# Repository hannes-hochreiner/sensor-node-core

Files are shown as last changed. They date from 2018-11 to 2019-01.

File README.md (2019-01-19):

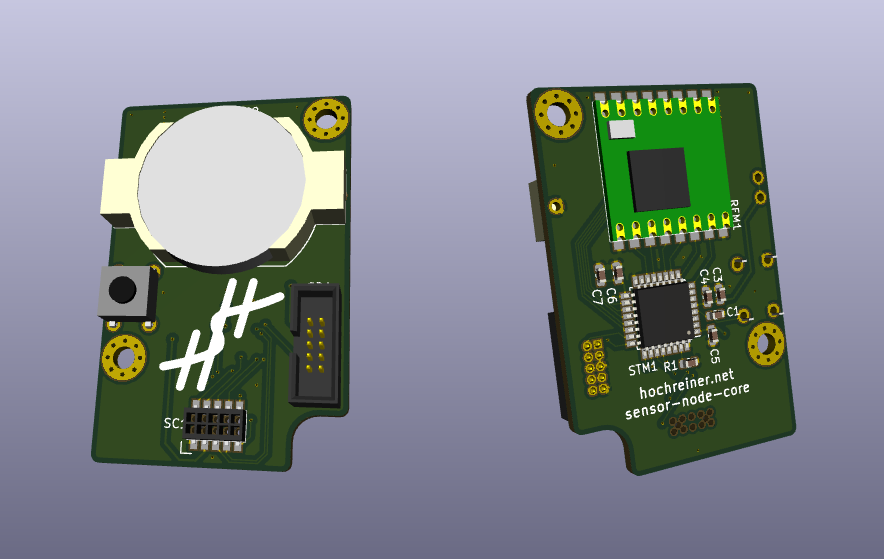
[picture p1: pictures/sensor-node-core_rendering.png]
kicad rendering of the sensor node core


# Sensor Node Core

This is another take on the sensor node theme.
I am planning on separating the core form the actual sensor.
The core will contain the micro-controller (incl. debug connector and reset button), radio (incl. antenna), and battery, as well as a connector providing power, SPI, I2C, and GPIOs.

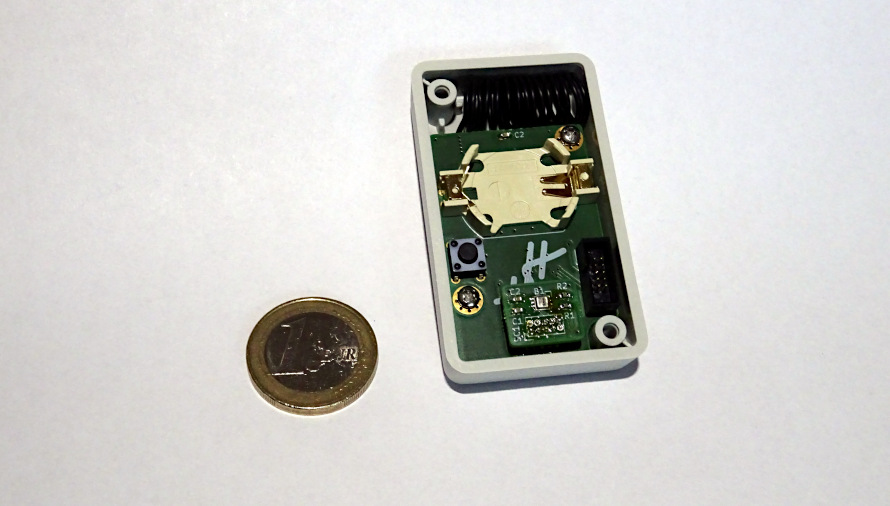
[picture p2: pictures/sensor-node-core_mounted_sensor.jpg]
sensor node core mounted in a plastic box with sensor


## Main parts

### STM32
  * STMicroelectronics: STM32L021K4T6
  * Digi-Key: [497-17903-ND](https://www.digikey.de/product-detail/de/stmicroelectronics/STM32L021K4T6/497-17903-ND)
  * [datasheet](http://www.st.com/content/ccc/resource/technical/document/datasheet/86/a6/5f/95/33/50/4e/d6/DM00206858.pdf/files/DM00206858.pdf/jcr:content/translations/en.DM0020685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)
  * Sleep Current: 0.54 µA
  * Price: 1.87

### RFM98
  * Seeed Technology Co., Ltd: 109990165
  * Digi-Key: [1597-1491-ND](https://www.digikey.de/product-detail/de/seeed-technology-co-ltd/109990165/1597-1491-ND)
  * [datasheet](https://github.com/SeeedDocument/RFM95-98_LoRa_Module/blob/master/RFM95_96_97_98_DataSheet.pdf)
  * Sleep Current: 0.2 µA
  * Price: 6.05

### Box
  * Hammond Manufacturing: 1551JGY
  * Digi-Key: [HM1133-ND](https://www.digikey.de/product-detail/de/hammond-manufacturing/1551JGY/HM1133-ND/2094871)
  * [Datasheet](http://www.hammondmfg.com/pdf/1551J.pdf)
  * Price: 2.09

### SWD Connector
  * CNC Tech: 3220-10-0100-00
  * Digi-Key: [1175-1627-ND](https://www.digikey.de/product-detail/en/cnc-tech/3220-10-0100-00/1175-1627-ND/3883661)
  * Price: 0.51

### 10-pin Sensor Connector
  * Harwin Inc.: M50-3150542R
  * Digi-Key: [952-3493-1-ND](https://www.digikey.de/product-detail/en/harwin-inc/M50-3150542R/952-3493-1-ND/6797677)
  * [Datasheet](https://cdn.harwin.com/pdfs/M50-315R.pdf)
  * Price: 2.27

### Coin Cell Holder
  * MPD (Memory Protection Devices): BU2032-1-G
  * Digi-Key: [BU2032-1-G-ND](https://www.digikey.de/product-detail/en/mpd-memory-protection-devices/BU2032-1-G/BU2032-1-G-ND/2439519)
  * [Datasheet](http://www.memoryprotectiondevices.com/datasheets/BU2032-1-G-datasheet.pdf)
  * Price: 0.89

### Button
  * TE Connectivity ALCOSWITCH Switches: 1825910-6
  * Digi-Key: [450-1650-ND](https://www.digikey.de/product-detail/en/te-connectivity-alcoswitch-switches/1825910-6/450-1650-ND/1632536)
  * [Datasheet](https://www.te.com/commerce/DocumentDelivery/DDEController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)
  * Price: 0.09

## Price

Estimate: about 20 EUR

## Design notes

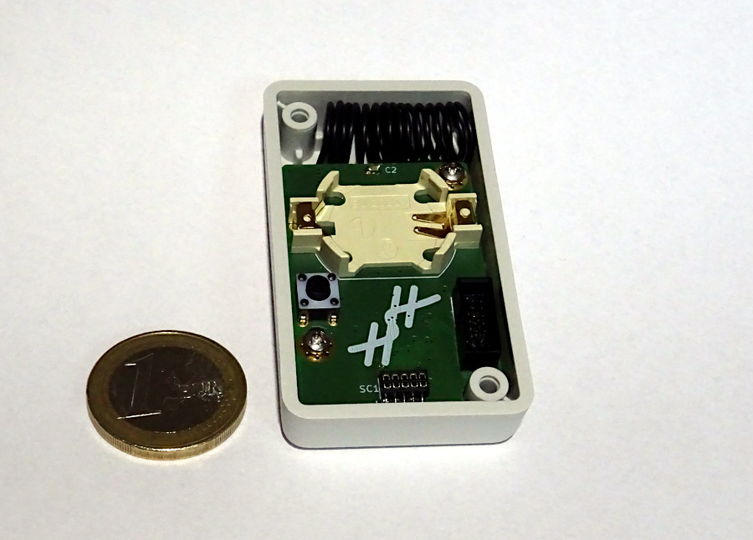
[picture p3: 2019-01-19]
pictures/sensor-node-core_mounted.jpg

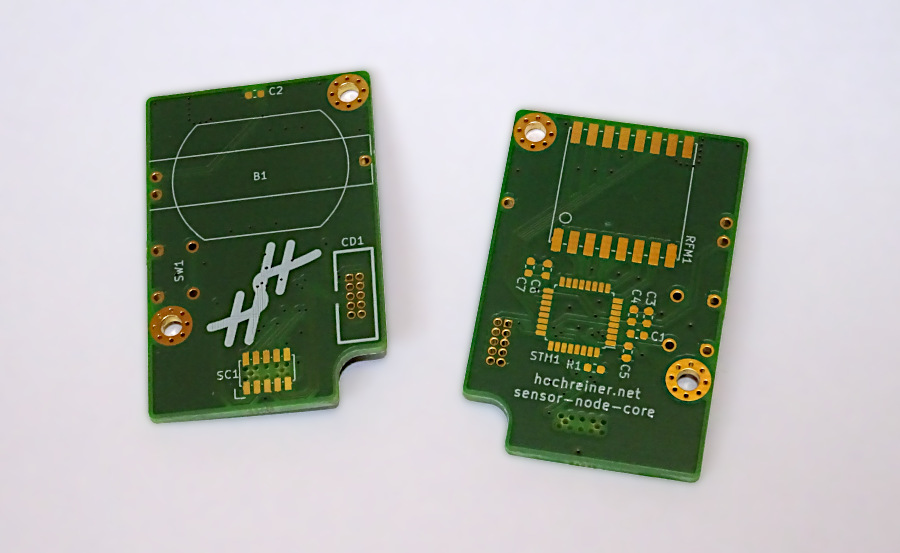
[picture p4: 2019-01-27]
pictures/sensor-node-core_pcb.jpg

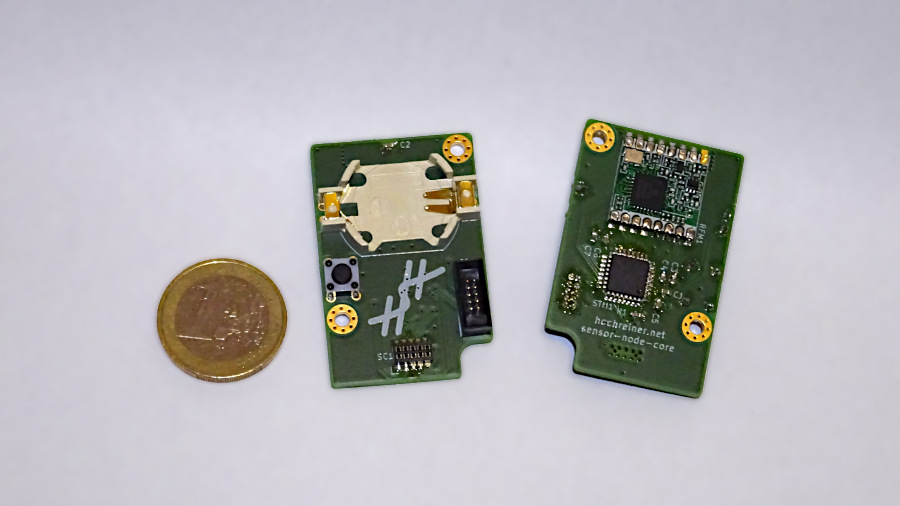
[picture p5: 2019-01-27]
pictures/sensor-node-core_populated.jpg

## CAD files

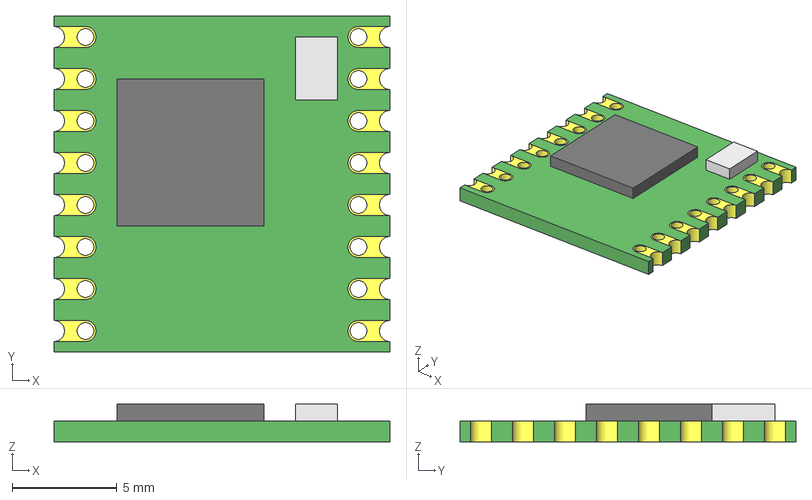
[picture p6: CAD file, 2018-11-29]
freecad/RFM98.step
16.0 x 16.0 x 1.80 mm

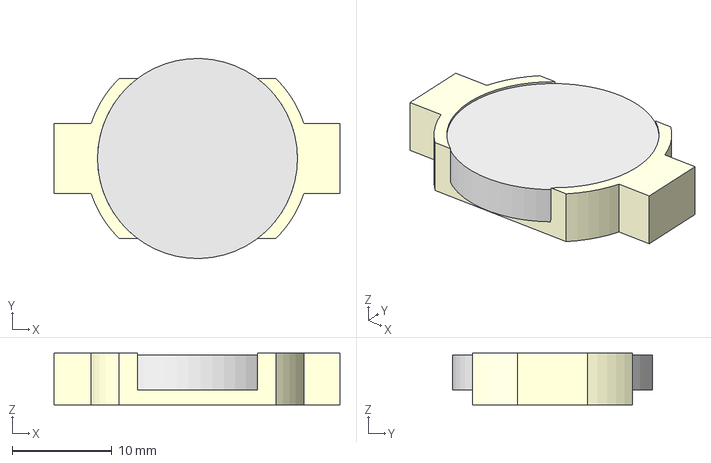
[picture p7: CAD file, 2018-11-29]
freecad/BU2032-1-G.step
28.6 x 20.0 x 5.20 mm

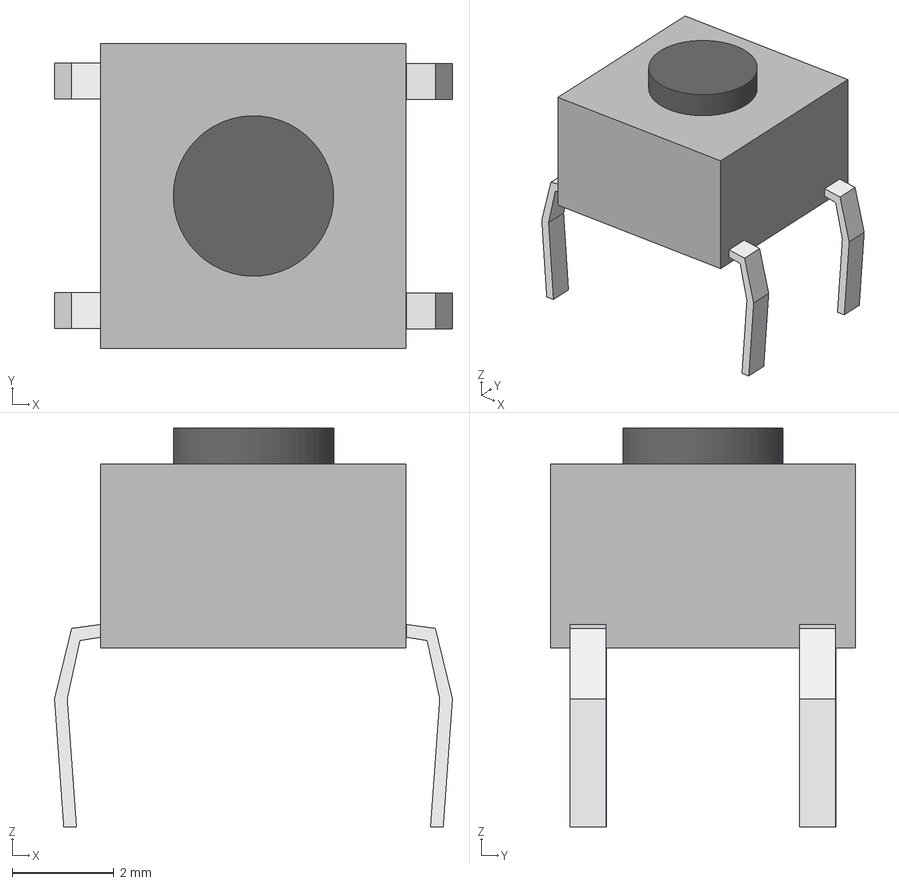
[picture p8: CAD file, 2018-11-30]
freecad/1825910-6.step
7.81 x 5.99 x 7.82 mm

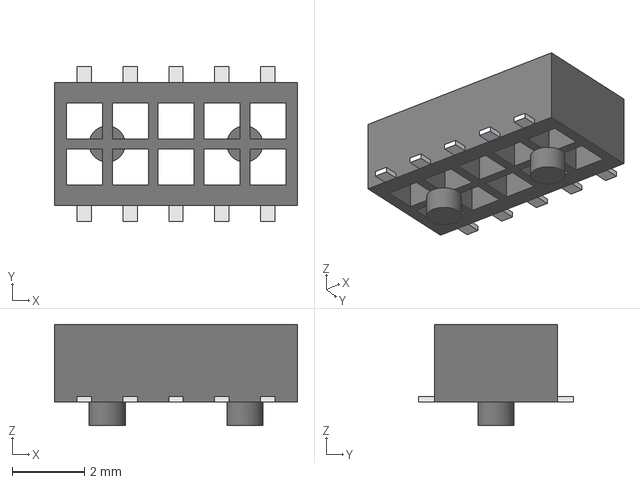
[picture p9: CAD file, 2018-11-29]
freecad/M50-3150542R.step
6.73 x 4.30 x 2.80 mm

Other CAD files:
freecad/1825910-6.fcstd
freecad/BU2032-1-G.fcstd
freecad/M50-3150542R.fcstd
freecad/RFM98.fcstd

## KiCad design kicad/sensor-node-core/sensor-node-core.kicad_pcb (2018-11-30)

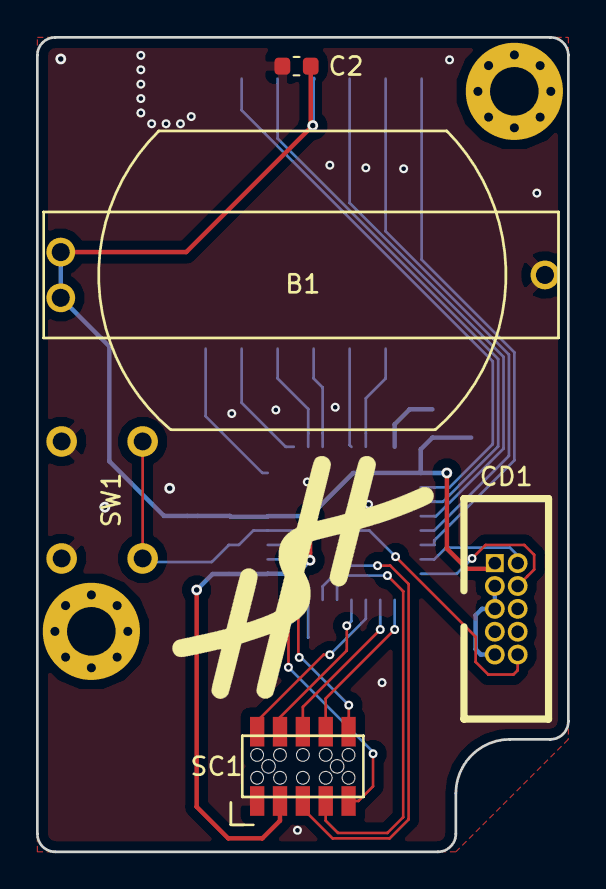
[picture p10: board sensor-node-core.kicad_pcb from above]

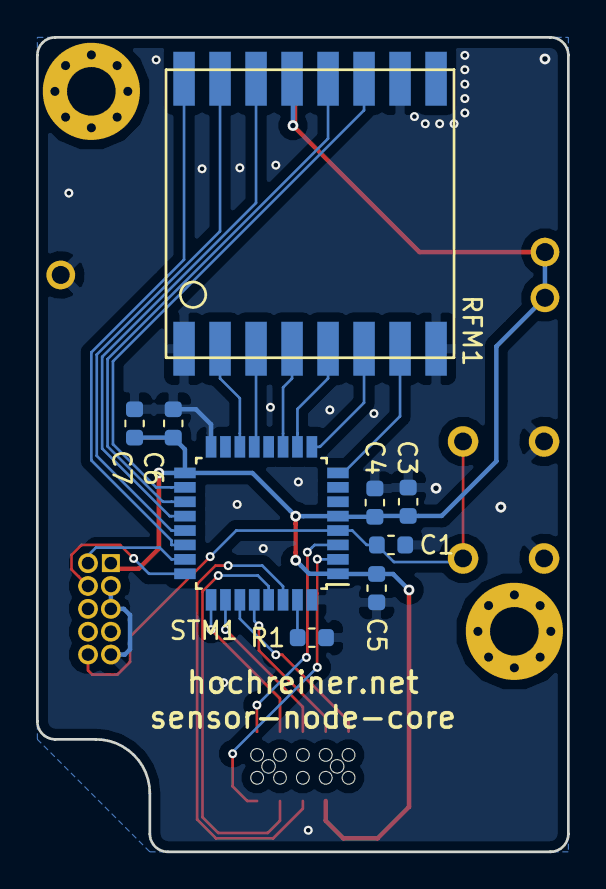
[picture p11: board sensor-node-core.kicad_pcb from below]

Board: 2 copper layers, 29.5 x 45.2 mm, 14 parts (9 on the bottom side), 25 nets.

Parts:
B1: BU2032-1-G
C1, C2, C4, C5, C6: 0.1µF; C_0603_1608Metric
C3: 1µF; C_0603_1608Metric
C7: 10µF; C_0603_1608Metric
CD1: CORTEX-DEBUG
R1: 10k; C_0603_1608Metric
RFM1: RFM98
SC1: Sensor-Connector; M50-3150542R
STM1: STM32L021K4T6; LQFP-32_7x7mm_P0.8mm
SW1: SW_Push; switch

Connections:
/3V3: B1.1, C2.1, C3.1, C4.1, C5.2, C6.1, C7.1, CD1.1, RFM1.13, SC1.3, STM1.1, STM1.5, STM1.17
/RFM_DIO0: RFM1.14, STM1.20
/RFM_DIO1: RFM1.15, STM1.21
/RFM_DIO2: RFM1.16, STM1.22
/RFM_DIO3: RFM1.11, STM1.18
/RFM_DIO4: RFM1.12, STM1.19
/RFM_DIO5: RFM1.7, STM1.8
/RFM_RESET: RFM1.6, STM1.9
/RFM_SPI_CLK: RFM1.4, STM1.11
/RFM_SPI_MISO: RFM1.2, STM1.14
/RFM_SPI_MOSI: RFM1.3, STM1.13
/SEN_GPIO_1: SC1.9, STM1.2
/SEN_GPIO_2: SC1.10, STM1.3
/SEN_I2C_SCL: SC1.7, STM1.29
/SEN_I2C_SDA: SC1.5, STM1.30
/SEN_SPI_CLK: SC1.6, STM1.26
/SEN_SPI_MISO: SC1.2, STM1.27
/SEN_SPI_MOSI: SC1.4, STM1.28
/SWD_CLK: CD1.4, STM1.24
/SWD_IO: CD1.2, STM1.23
/~RFM_SPI_CS: RFM1.5, STM1.10
/~SEN_SPI_CS: SC1.8, STM1.25
/~SWD_RST: C1.1, CD1.10, STM1.4, SW1.2
GND: B1.2, C1.2, C2.2, C3.2, C4.2, C5.1, C6.2, C7.2, CD1.3, CD1.5, CD1.9, R1.2, RFM1.1, RFM1.8, RFM1.10, SC1.1, STM1.16, STM1.32, SW1.1
unnamed: R1.1, STM1.31

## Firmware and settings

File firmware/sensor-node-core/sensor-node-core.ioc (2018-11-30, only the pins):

Mcu.UserName=STM32L021K4Tx
PA10.GPIO_Label=RFM_GPIO_0
PA10.Signal=GPIO_Input
PA11.GPIO_Label=RFM_GPIO_1
PA11.Signal=GPIO_Input
PA12.GPIO_Label=RFM_GPIO_2
PA12.Signal=GPIO_Input
PA13.Signal=SYS_SWDIO
PA14.Signal=SYS_SWCLK
PA15.GPIO_Label=SEN_SPI_NCS
PA15.Signal=GPIO_Input
PA2.GPIO_Label=RFM_GPIO_5
PA2.Signal=GPIO_Input
PA3.GPIO_Label=RFM_RESET
PA3.Signal=GPIO_Output
PA4.Signal=SPI1_NSS
PA5.Signal=SPI1_SCK
PA7.Signal=SPI1_MOSI
PA8.GPIO_Label=RFM_GPIO_3
PA8.Signal=GPIO_Input
PA9.GPIO_Label=RFM_GPIO_4
PA9.Signal=GPIO_Input
PB0.Signal=SPI1_MISO
PB3.GPIO_Label=SEN_SPI_CLK
PB3.Signal=GPIO_Input
PB4.GPIO_Label=SEN_SPI_MISO
PB4.Signal=GPIO_Input
PB5.GPIO_Label=SEN_SPI_MOSI
PB5.Signal=GPIO_Output
PB6.Signal=I2C1_SCL
PB7.Signal=I2C1_SDA
PC14-OSC32_IN.GPIO_Label=SEN_GPIO_1
PC14-OSC32_IN.Signal=GPIO_Input
PC15-OSC32_OUT.GPIO_Label=SEN_GPIO_2
PC15-OSC32_OUT.Signal=GPIO_Input

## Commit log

2018-11-29 added footprints
    [BU2032-1-G.fcstd, BU2032-1-G.step, sensor-node-core.kicad_pcb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]
2018-11-29 added schematic
    [M50-3150542R.fcstd, M50-3150542R.step, RFM98.fcstd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]
2018-11-30 updated switch model and layout
    [1825910-6.fcstd, 1825910-6.step, sensor-node-core.kicad_pcb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]
2018-11-30 added firmware folder and routing
    [sensor-node-core.kicad_pcb, sensor-node-core.sch]
2018-11-30 added label and logo
    [sensor-node-core.kicad_pcb]
2018-12-01 added a rendering of the board
2019-01-19 added images of the sensor node core
